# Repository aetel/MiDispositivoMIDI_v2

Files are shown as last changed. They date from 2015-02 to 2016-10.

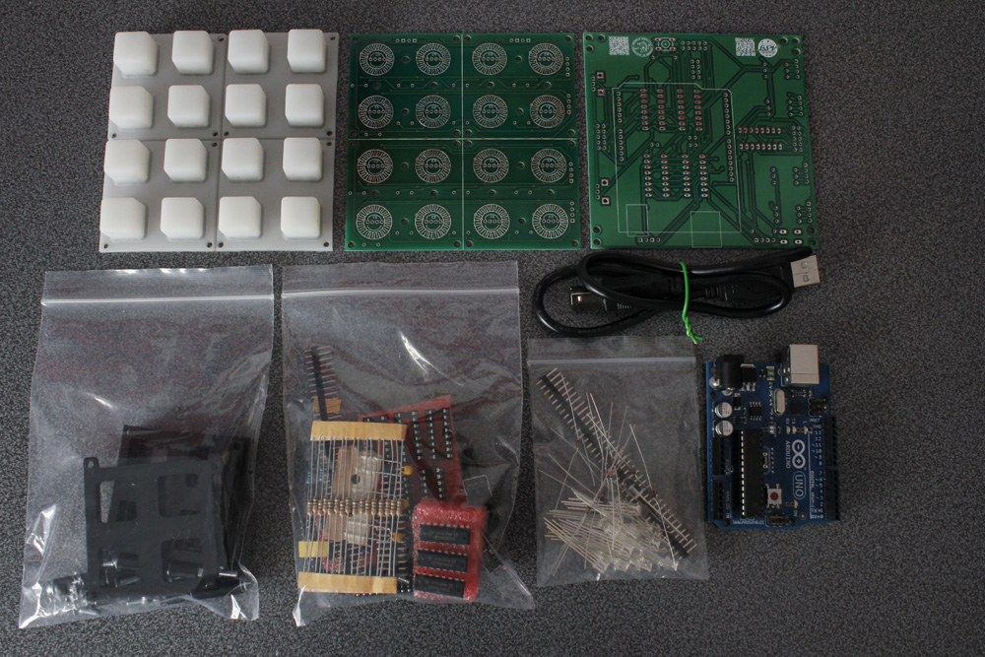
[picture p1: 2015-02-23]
Pictures/00_materials.jpg

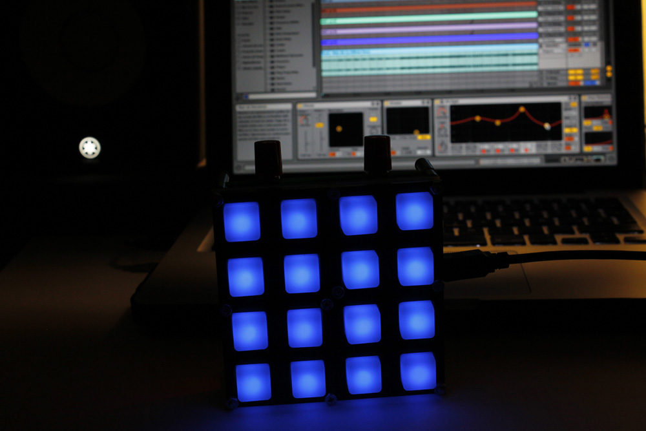
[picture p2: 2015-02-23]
_assembled.jpg

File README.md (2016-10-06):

# Warning
This repository is no loger active. Everything has been moved to the BanaNut Electronics repository:
https://github.com/bananutelectronics

# MiDispositivoMIDI_v2
MiDispositivoMIDI is a DIY MIDI Controller developed by a couple students of the Polytechnic University of Madrid for a workshop given in May and October of 2014. The code is under MIT license and the hardware is under CC BY-NC-SA 4.0. Everything can be downloaded from this repository. If you are interested in helping us to improve our proyect, let us know!

# https://www.facebook.com/midispositivomidi
# midispositivomidi@gmail.com

# Hardware License
<br /><span xmlns:dct="http://purl.org/dc/terms/" property="dct:title">MiDispositivoMIDI</span> by <a xmlns:cc="http://creativecommons.org/ns#" href="https://github.com/midispositivomidi" property="cc:attributionName" rel="cc:attributionURL">Alvaro Lopez Revuelta & Pablo de Miguel Morales</a> is licensed under a <a rel="license" href="http://creativecommons.org/licenses/by-nc-sa/4.0/">Creative Commons Attribution-NonCommercial-ShareAlike 4.0 International License</a>.<br />Permissions beyond the scope of this license may be available at <a xmlns:cc="http://creativecommons.org/ns#" href="https://github.com/midispositivomidi" rel="cc:morePermissions">https://github.com/midispositivomidi</a>.

# Important notes
Note that this Arduino library also uses other libraries. You will need to download the following:
analogmuxdemux.h
SimpleTimer.h
Keypad.h
MIDI.h

# Features
This initial release has four examples in order to show the main features of the library. A brief explanation is given in the header of each example. Basically it shows how to light up the leds, send midi messages and use timmers.

# ChangeLog
-23rd February 2014, v2.0 initial release.

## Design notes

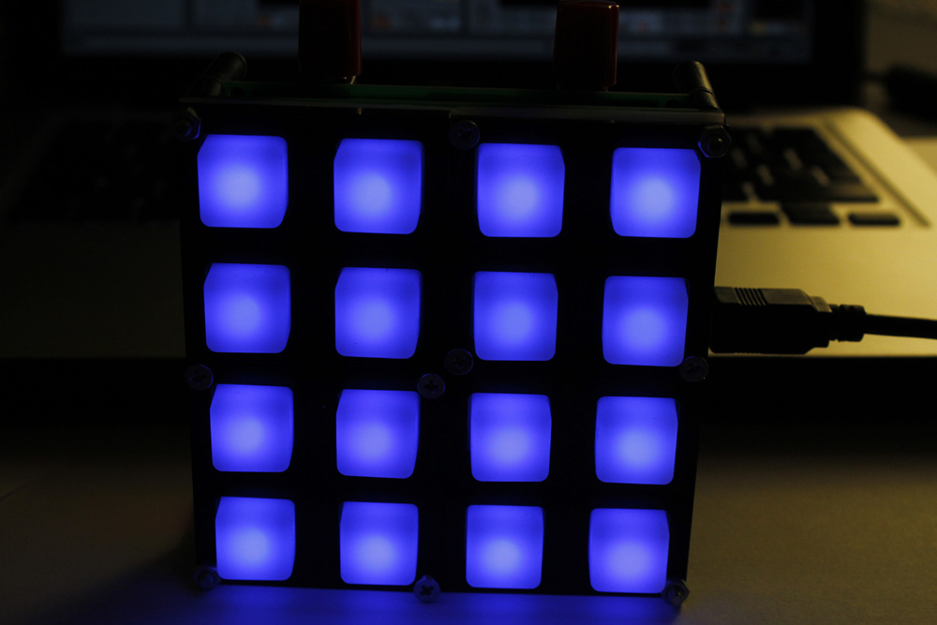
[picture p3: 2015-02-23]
Pictures/00_device.jpg

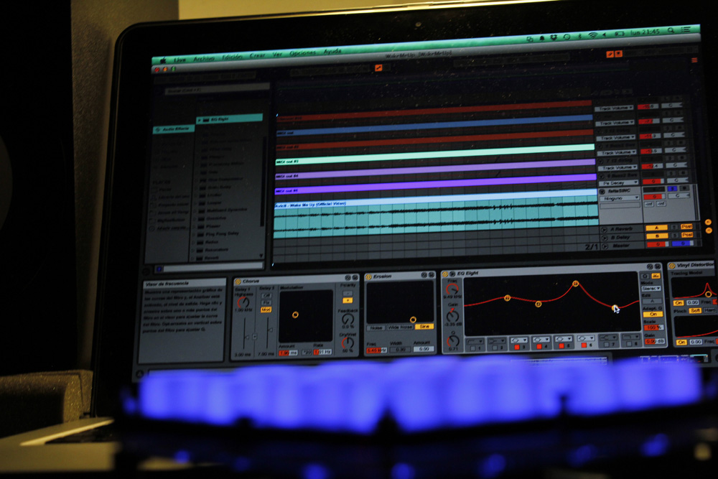
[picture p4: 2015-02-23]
Pictures/00_live2.jpg

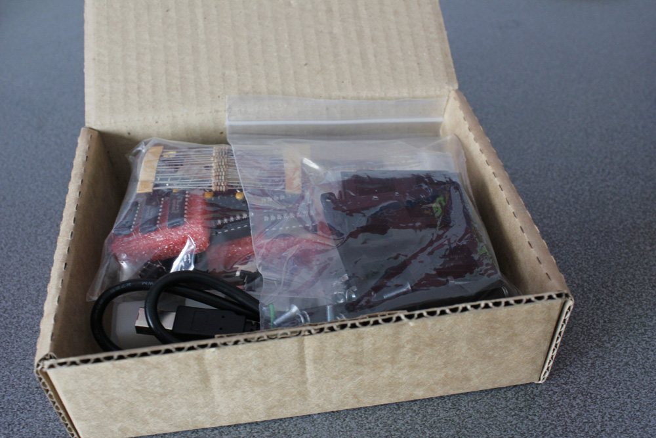
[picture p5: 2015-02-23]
Pictures/00_box.jpg

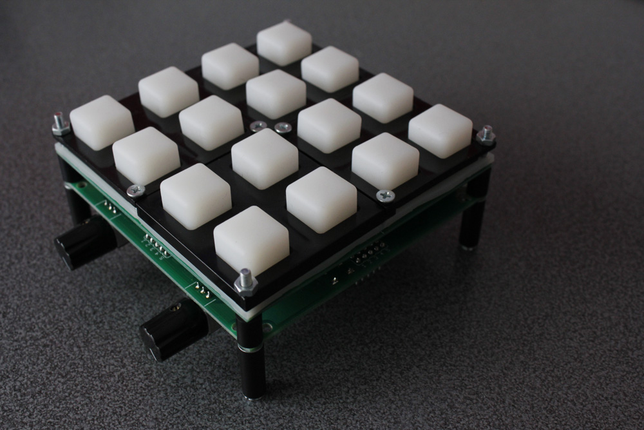
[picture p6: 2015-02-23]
Pictures/00_assempbled.jpg

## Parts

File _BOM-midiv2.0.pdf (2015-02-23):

# Bill of Materials MiDispositivoMidi v2.0

Item | Supplier
x16 LED RGB Diffuse Common Anode | *
x16 Diodes 1N4148 | *
x01 Pin Male (Single row) | *
x02 Male Pin Row (Single and Double) | *
x01 Female Pin Row | *
x01 Top PCB SparkFun | SparkFun website
x01 Bottom PCB | Can’t be bought. See Eagle files
x01 Silicon ButtonPad | SparkFun website
x04 2x2 Bezel | SparkFun website
x06 Screws M3 15mm | *
x04 Screws M3 45mm | *
x04 Tube M3 20mm | *
x04 Tube M3 10mm | *
x10 M3 Nut | *
x08 M3 Washer | *
x02 5k Potentiometer | *
x02 Knob | *
x16 Resistor 220Ohm | *
x02 Resistor 10kOhm | *
x05 DIP 8 | *
x02 Shift Register 74HC595 | *
x03 Multiplexer 4051 | *
x03 Capacitor 0.1uF | *
x02 Switch | *
x02 Jumper | *
x01 Arduino UNO + Cable | *

### *Rows

### marked

### with

an

### asterisk

### can

be

### bought

in

### any

### electronics

### shop. For

### more information

### see

### Eagle

### schematics

or

### MiDispositivoMIDI

guide,

### which

### contains pictures

of

everything.

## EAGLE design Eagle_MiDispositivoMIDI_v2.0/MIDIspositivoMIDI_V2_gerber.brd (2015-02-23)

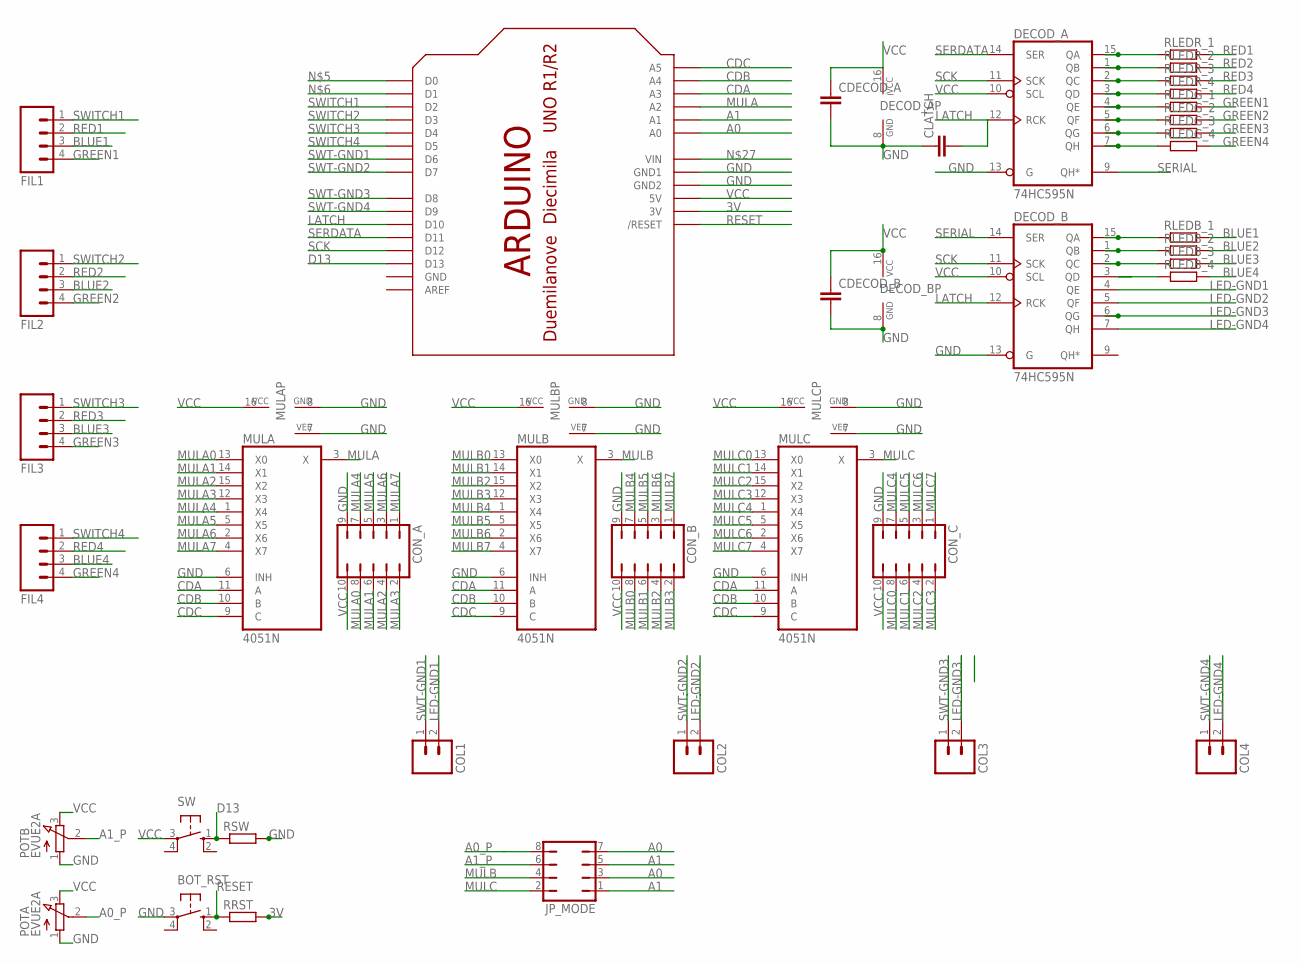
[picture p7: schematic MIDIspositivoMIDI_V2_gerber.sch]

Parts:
BOT_RST: 10-XX; B3F-10XX
CDECOD_A: C-EU025-030X050; C025-030X050
CDECOD_B: C-EU025-030X050; C025-030X050
CLATCH: C-EU025-030X050; C025-030X050
COL1, COL2, COL3, COL4: M02POLAR; MOLEX-1X2
CON_A: JP5Q
CON_B: JP5Q
CON_C: JP5Q
DECOD_A: 74HC595N; DIL16
DECOD_B: 74HC595N; DIL16
FIL1, FIL2, FIL3, FIL4: M04POLAR; MOLEX-1X4
JP_MODE: JP4Q
MULA: 4051N; DIL16
MULB: 4051N; DIL16
MULC: 4051N; DIL16
POTA: EVUE2A; EVUE
POTB: EVUE2A; EVUE
RLEDB_1, RLEDB_2, RLEDB_3, RLEDB_4: R-EU_0207/10; 0207/10
RLEDG_1, RLEDG_2, RLEDG_3, RLEDG_4: R-EU_0207/10; 0207/10
RLEDR_1, RLEDR_2, RLEDR_3, RLEDR_4: R-EU_0207/10; 0207/10
RRST: R-EU_0207/10; 0207/10
RSW: R-EU_0207/10; 0207/10
SW: 10-XX; B3F-10XX
U$1: ARDUINO-NOHOLE

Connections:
3V: RRST.2, U$1.3V
A0: JP_MODE.3, JP_MODE.7, U$1.A0
A0_P: JP_MODE.8, POTA.2 (S)
A1: JP_MODE.1, JP_MODE.5, U$1.A1
A1_P: JP_MODE.6, POTB.2 (S)
BLUE1: FIL1.3, RLEDB_1.2
BLUE2: FIL2.3, RLEDB_2.2
BLUE3: FIL3.3, RLEDB_3.2
BLUE4: FIL4.3, RLEDB_4.2
CDA: MULA.11 (A), MULB.11 (A), MULC.11 (A), U$1.A3
CDB: MULA.10 (B), MULB.10 (B), MULC.10 (B), U$1.A4
CDC: MULA.9 (C), MULB.9 (C), MULC.9 (C), U$1.A5
D13: RSW.1, SW.1 (S), U$1.D13
GND: BOT_RST.3, CDECOD_A.2, CDECOD_B.2, CLATCH.1, CON_A.9, CON_B.9, CON_C.9, DECOD_A.8 (GND), DECOD_A.13 (G), DECOD_B.8 (GND), DECOD_B.13 (G), MULA.6 (INH), MULA.7 (VEE), MULA.8 (GND), MULB.6 (INH), MULB.7 (VEE), MULB.8 (GND), MULC.6 (INH), MULC.7 (VEE), MULC.8 (GND), POTA.1 (A), POTB.1 (A), RSW.2, U$1.GND, U$1.GND1, U$1.GND2
GREEN1: FIL1.4, RLEDG_1.2
GREEN2: FIL2.4, RLEDG_2.2
GREEN3: FIL3.4, RLEDG_3.2
GREEN4: FIL4.4, RLEDG_4.2
LATCH: CLATCH.2, DECOD_A.12 (RCK), DECOD_B.12 (RCK), U$1.D10
LED-GND1: COL1.2, DECOD_B.4 (QE)
LED-GND2: COL2.2, DECOD_B.5 (QF)
LED-GND3: COL3.2, DECOD_B.6 (QG)
LED-GND4: COL4.2, DECOD_B.7 (QH)
MULA: MULA.3 (X), U$1.A2
MULA0: CON_A.8, MULA.13 (X0)
MULA1: CON_A.6, MULA.14 (X1)
MULA2: CON_A.4, MULA.15 (X2)
MULA3: CON_A.2, MULA.12 (X3)
MULA4: CON_A.7, MULA.1 (X4)
MULA5: CON_A.5, MULA.5 (X5)
MULA6: CON_A.3, MULA.2 (X6)
MULA7: CON_A.1, MULA.4 (X7)
MULB: JP_MODE.4, MULB.3 (X)
MULB0: CON_B.8, MULB.13 (X0)
MULB1: CON_B.6, MULB.14 (X1)
MULB2: CON_B.4, MULB.15 (X2)
MULB3: CON_B.2, MULB.12 (X3)
MULB4: CON_B.7, MULB.1 (X4)
MULB5: CON_B.5, MULB.5 (X5)
MULB6: CON_B.3, MULB.2 (X6)
MULB7: CON_B.1, MULB.4 (X7)
MULC: JP_MODE.2, MULC.3 (X)
MULC0: CON_C.8, MULC.13 (X0)
MULC1: CON_C.6, MULC.14 (X1)
MULC2: CON_C.4, MULC.15 (X2)
MULC3: CON_C.2, MULC.12 (X3)
MULC4: CON_C.7, MULC.1 (X4)
MULC5: CON_C.5, MULC.5 (X5)
MULC6: CON_C.3, MULC.2 (X6)
MULC7: CON_C.1, MULC.4 (X7)
unnamed: DECOD_A.15 (QA), RLEDR_1.1
unnamed: DECOD_A.1 (QB), RLEDR_2.1
unnamed: DECOD_A.2 (QC), RLEDR_3.1
unnamed: DECOD_A.3 (QD), RLEDR_4.1
unnamed: DECOD_A.4 (QE), RLEDG_1.1
unnamed: DECOD_A.5 (QF), RLEDG_2.1
unnamed: DECOD_A.6 (QG), RLEDG_3.1
unnamed: DECOD_A.7 (QH), RLEDG_4.1
unnamed: DECOD_B.15 (QA), RLEDB_1.1
unnamed: DECOD_B.1 (QB), RLEDB_2.1
unnamed: DECOD_B.2 (QC), RLEDB_3.1
unnamed: DECOD_B.3 (QD), RLEDB_4.1
RED1: FIL1.2, RLEDR_1.2
RED2: FIL2.2, RLEDR_2.2
RED3: FIL3.2, RLEDR_3.2
RED4: FIL4.2, RLEDR_4.2
RESET: BOT_RST.1 (S), RRST.1, U$1.RESET (/RESET)
SCK: DECOD_A.11 (SCK), DECOD_B.11 (SCK), U$1.D12
SERDATA: DECOD_A.14 (SER), U$1.D11
SERIAL: DECOD_A.9 (QH*), DECOD_B.14 (SER)
SWITCH1: FIL1.1, U$1.D2
SWITCH2: FIL2.1, U$1.D3
SWITCH3: FIL3.1, U$1.D4
SWITCH4: FIL4.1, U$1.D5
SWT-GND1: COL1.1, U$1.D6
SWT-GND2: COL2.1, U$1.D7
SWT-GND3: COL3.1, U$1.D8
SWT-GND4: COL4.1, U$1.D9
VCC: CDECOD_A.1, CDECOD_B.1, CON_A.10, CON_B.10, CON_C.10, DECOD_A.10 (SCL), DECOD_A.16 (VCC), DECOD_B.10 (SCL), DECOD_B.16 (VCC), MULA.16 (VCC), MULB.16 (VCC), MULC.16 (VCC), POTA.3 (E), POTB.3 (E), SW.3, U$1.5V

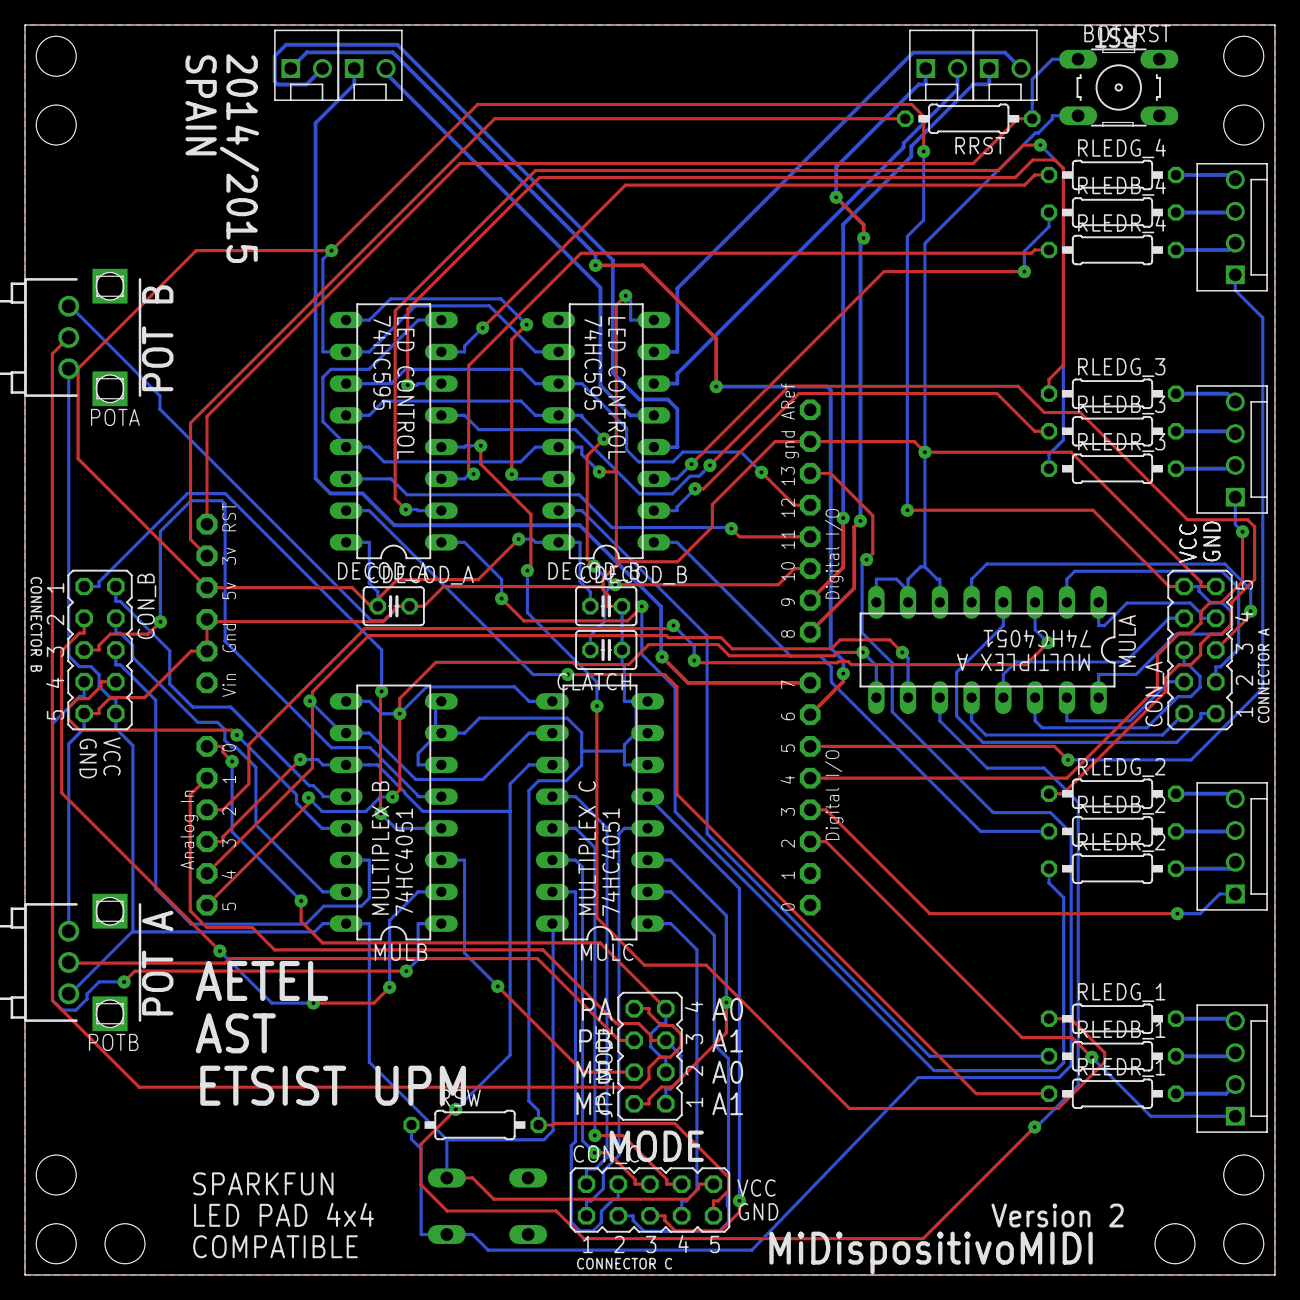
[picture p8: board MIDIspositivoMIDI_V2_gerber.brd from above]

Board: 2 copper layers, 100.0 x 100.0 mm, 39 parts (1 on the bottom side), 79 nets.

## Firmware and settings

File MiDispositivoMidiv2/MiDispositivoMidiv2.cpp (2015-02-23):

#include "Arduino.h"
#include "MiDispositivoMidiv2.h"

const int latchPin = 10;
const int dataPin = 11;
const int clockPin = 12;

// Estas variables almacenaran en hexadecimal los valores necesarios
// para representar en los led lo que se quiera
char parteAlta = 0x00;
char parteBaja = 0x00;


byte dataArrayRG[4]; // Datos RED GREEN
byte dataArrayBC[4]; // Datos BLUE y COL
byte dataRG;
byte dataBC;
#define RED 1
#define BLU 0
#define GRN 2
int anodoComun = 1;  //cambiar anodo o catodo comun.  anodo =1

// Almacenara los valores de los led que se quieran encender
int ledMatrix[4][4][3]={
    {{0,0,0},{0,0,0},{0,0,0},{0,0,0},}, // RGB
    {{0,0,0},{0,0,0},{0,0,0},{0,0,0},},
    {{0,0,0},{0,0,0},{0,0,0},{0,0,0},},
    {{0,0,0},{0,0,0},{0,0,0},{0,0,0},},
};

// Constructor de nuestro dispositivo
MiDispositivoMidiv2::MiDispositivoMidiv2()
{
    // Se ponen asignan los pines para los registros de desplazamiento como salidas
    pinMode(latchPin, OUTPUT);
    pinMode(dataPin, OUTPUT);
    pinMode(clockPin, OUTPUT);
    //Se encinden los leds con el valor inicial de las variables
    // parteAlta y parteBaja. Este valor hace que esten apagados
}


//--------------PARA LOS LEDS---------------------//

void MiDispositivoMidiv2::setCommonAnode(){
    anodoComun = 1;
}
void MiDispositivoMidiv2::setCommonCathode(){
    anodoComun = 0;
}

void MiDispositivoMidiv2::turnOn(){
    //Apaga la salida para que al realizar el desplazamiento no se vea
    digitalWrite(latchPin, LOW);
    //Lleva los datos a los registros
    if(!anodoComun){  //si es de catodo comun en vez de anodo comun
        parteBaja = ~parteBaja;
        parteAlta = ~parteAlta;
    }
    shiftOut(dataPin, clockPin, LSBFIRST, parteBaja);
    shiftOut(dataPin, clockPin, LSBFIRST, parteAlta);
    // turn on the output so the LEDs can light up:
    digitalWrite(latchPin, HIGH);
}
//Lleva a los registros de desplazamiento todos los datos necesarios para iluminar los leds
void MiDispositivoMidiv2::setLed(char alta, char baja){
    parteAlta=alta;
    parteBaja=baja;
    turnOn();
}
//Enciende todo de un mismo color
void MiDispositivoMidiv2::lightUpAll(char color){
    if(color=='b'){
        setLed(0xF0,0xFF);
    }
    if(color=='r'){
        setLed(0x0F,0xFF);
    }
    if(color=='g'){
        setLed(0xFF,0x0F);
    }
    if(color=='y'){
        setLed(0x0F,0x0F);
    }
    if(color=='m'){
        setLed(0x00,0xFF);
    }
    if(color=='c'){
        setLed(0xF0,0x0F);
    }
    if(color=='w'){
        setLed(0x00,0x0F);
    }
}
//Enciende una fila de un determinado color
void MiDispositivoMidiv2::lightUpRow(char color, int fila ){
    if(color=='b'){ //Color azul
        if(fila==1){setLed(0xFE,0xFF);}
        if(fila==2){setLed(0xFD,0xFF);}
        if(fila==3){setLed(0xFB,0xFF);}
        if(fila==4){setLed(0xF7,0xFF);}
    }if(color=='r'){ //Color rojo
        if(fila==1){setLed(0xEF,0xFF);}
        if(fila==2){setLed(0xDF,0xFF);}
        if(fila==3){setLed(0xBF,0xFF);}
        if(fila==4){setLed(0x7F,0xFF);}
    }if(color=='g'){ //Color verde
        if(fila==1){setLed(0xFF,0xEF);}
        if(fila==2){setLed(0xFF,0xDF);}
        if(fila==3){setLed(0xFF,0xBF);}
        if(fila==4){setLed(0xFF,0x7F);}
    }
    if(color=='y'){ //Color amarillo = verde + rojo
        if(fila==1){setLed(0xEF,0xEF);}
        if(fila==2){setLed(0xDF,0xDF);}
        if(fila==3){setLed(0xBF,0xBF);}
        if(fila==4){setLed(0x7F,0x7F);}
    }
    if(color=='m'){ //Color magenta = rojo + azul
        if(fila==1){setLed(0xEE,0xFF);}
        if(fila==2){setLed(0xDD,0xFF);}
        if(fila==3){setLed(0xBB,0xFF);}
        if(fila==4){setLed(0x77,0xFF);}
    }
    if(color=='c'){ //Color cyan = verde + azul
        if(fila==1){setLed(0xFE,0xEF);}
        if(fila==2){setLed(0xFD,0xDF);}
        if(fila==3){setLed(0xFB,0xBF);}
        if(fila==4){setLed(0xF7,0x7F);}
    }
    if(color=='w'){ //Color blanco = verde + rojo + azul
        if(fila==1){setLed(0xEE,0xEF);}
        if(fila==2){setLed(0xDD,0xDF);}
        if(fila==3){setLed(0xBB,0xBF);}
        if(fila==4){setLed(0x77,0x7F);}
    }
}

//Enciende una columna de un determinado color
void MiDispositivoMidiv2::lightUpCol(char color, int columna){
    if(color=='b'){ //Color azul
        if(columna==1){setLed(0xF0,0xF8);}
        if(columna==2){setLed(0xF0,0xF4);}
        if(columna==3){setLed(0xF0,0xF2);}
        if(columna==4){setLed(0xF0,0xF1);}
    }if(color=='r'){ //Color rojo
        if(columna==1){setLed(0x0F,0xF8);}
        if(columna==2){setLed(0x0F,0xF4);}
        if(columna==3){setLed(0x0F,0xF2);}
        if(columna==4){setLed(0x0F,0xF1);}
    }if(color=='g'){ //Color verde
        if(columna==1){setLed(0xFF,0x08);}
        if(columna==2){setLed(0xFF,0x04);}
        if(columna==3){setLed(0xFF,0x02);}
        if(columna==4){setLed(0xFF,0x01);}
    }
    if(color=='y'){ //Color amarillo = verde + rojo
        if(columna==1){setLed(0x0F,0x08);}
        if(columna==2){setLed(0x0F,0x04);}
        if(columna==3){setLed(0x0F,0x02);}
        if(columna==4){setLed(0x0F,0x01);}
    }
    if(color=='m'){ //Color magenta = rojo + azul
        if(columna==1){setLed(0x00,0xF8);}
        if(columna==2){setLed(0x00,0xF4);}
        if(columna==3){setLed(0x00,0xF2);}
        if(columna==4){setLed(0x00,0xF1);}
    }
    if(color=='c'){ //Color cyan = verde + azul
        if(columna==1){setLed(0xF0,0x08);}
        if(columna==2){setLed(0xF0,0x04);}
        if(columna==3){setLed(0xF0,0x02);}
        if(columna==4){setLed(0xF0,0x01);}
    }
    if(color=='w'){ //Color blanco = verde + azul + rojo
        if(columna==1){setLed(0x00,0x08);}
        if(columna==2){setLed(0x00,0x04);}
        if(columna==3){setLed(0x00,0x02);}
        if(columna==4){setLed(0x00,0x01);}
    }
}
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

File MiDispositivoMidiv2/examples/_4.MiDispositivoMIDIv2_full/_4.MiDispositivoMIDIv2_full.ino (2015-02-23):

/****-------------------- MIDISPOSITIVOMIDI V2.0 --------------------****
* This is a simple code to MiDispositivoMidi v2.0, a DIY MIDI Controller
* developed by Pablo de Miguel Morales and Alvaro Lopez Revuelta at the
* Polythecnical University of Madrid, for a workshop given in 2014.
* This code was developed by Alvaro Lopez Revuelta for the project MiDispositivoMidi v2.0
* and uses the function "formar_array" of Pablo de Miguel Morales
*
*                            Feel free to contact us:
*                            midispositivomidi@gmail.com
*                        https://github.com/midispositivomidi
*                     https://www.facebook.com/midispositivomidi
*           For further information about the license, visit us on GitHub                      
*
* Features of Example 4:
* It also uses our Arduino library (MiDispositivoMidiv2.h) for led handling
* The main functionalities are:
*    -Send MIDI Messages that can be setted by the user
*    -It has seven pages of notes/colors
*    -Pressed--->Send NoteOn
*    -Released-->Send NoteOff
*    -The user can also set the color of each page
*    -and the color of each pressed button
*/
#include <analogmuxdemux.h>
#include <SimpleTimer.h>
#include <MiDispositivoMidiv2.h>
#include <Keypad.h>
#include <MIDI.h>
#define NO_PINS 8
#define R 1
#define G 2
#define B 3
#define Y 4
#define C 5
#define M 6
#define W 7

/*--------------------------C U S T O M I Z E  T H E  C O D E---------------------------*/

/* In this arrays bellow, you can customize the code by selecting which note
*  wil be sent pressing each button, what colour do you want on each page, and
*  what colour do you want to light up when pressed. Also you can set how many
*  expansions you want to use (from 0 to 3);
*/

#define N_EXP 0                          //If 2 or 3 is selected, lateral pots (2) wont work
#define MAX_NUM_PAGES 7                  //Change the array length if you change this value
#define DEFAULT_PAGE 0                   //This is the page shown after botting (default page)
int led_pages[4][MAX_NUM_PAGES][4] = {   //Colour of each page when no button is pressed
 //pag 1    //pag 2   //pag 3   //pag 4   //pag 5   //pag 6   //pag 7
{{B,B,B,B},{G,G,G,G},{B,B,B,B},{Y,Y,Y,Y},{C,C,C,C},{M,M,M,M},{W,W,W,W}},
{{B,B,B,B},{G,G,G,G},{B,B,B,B},{Y,Y,Y,Y},{C,C,C,C},{M,M,M,M},{W,W,W,W}},
{{B,B,B,B},{G,G,G,G},{B,B,B,B},{Y,Y,Y,Y},{C,C,C,C},{M,M,M,M},{W,W,W,W}},
{{B,B,B,B},{G,G,G,G},{B,B,B,B},{Y,Y,Y,Y},{C,C,C,C},{M,M,M,M},{W,W,W,W}},
};

int led_pressed[4][MAX_NUM_PAGES][4] = {  //Colour when pressed. When released it will be the same as before
 //pag 1    //pag 2   //pag 3   //pag 4   //pag 5   //pag 6   //pag 7
{{G,G,G,G},{R,R,R,R},{R,R,R,R},{R,R,R,R},{R,R,R,R},{R,R,R,R},{R,R,R,R}},
{{G,G,G,G},{R,R,R,R},{R,R,R,R},{R,R,R,R},{R,R,R,R},{R,R,R,R},{R,R,R,R}},
{{G,G,G,G},{R,R,R,R},{R,R,R,R},{R,R,R,R},{R,R,R,R},{R,R,R,R},{R,R,R,R}},
{{G,G,G,G},{R,R,R,R},{R,R,R,R},{R,R,R,R},{R,R,R,R},{R,R,R,R},{R,R,R,R}},
};

int notes[4][MAX_NUM_PAGES][4] = {       //Here you can set which note do you want to send
  //pag 1       //pag 2        //pag 3       //pag 4       //pag 5      //pag 6       //pag 7
{{0 ,1 ,2 , 3},{16,17,18,19},{32,33,34,35},{48,49,50,51},{64,65,66,67},{80,81,82,83},{96 , 97 ,98 ,99}},
{{4 ,5 ,6 , 7},{20,21,22,23},{36,37,38,39},{52,53,54,55},{68,69,70,71},{84,85,86,87},{100,101,102,103}},
{{8 ,9 ,10,11},{24,25,26,27},{40,41,42,43},{56,57,58,59},{72,73,74,75},{88,89,90,91},{104,105,106,107}},
{{12,13,14,15},{28,29,30,31},{44,45,46,47},{60,61,62,63},{76,77,78,79},{92,93,94,95},{108,109,110,110}},
};
/* --------------------------end of customizing code---------------------------------------*/


uint16_t prev_expA[8]={0,0,0,0,0,0,0,0}; //Last value read of potExpansion A
uint16_t prev_expB[8]={0,0,0,0,0,0,0,0}; //Last value read of potExpansion B
uint16_t prev_expC[8]={0,0,0,0,0,0,0,0}; //Last value read of potExpansion C
int num_page = 0;                        //Current page (from 1 to 7)
int prev_integrated0 = 0;                //For integrated pots
int prev_integrated1 = 0;
int pushedRow=0;                         //Coordinate y of pressed button
int pushedCol=0;                         //Coordinate x of pressed button
int contador1 = 0;                       //Counter for one timmer
boolean shift_pushed =false;

AnalogMux Amux(17,18,19, 2); //EXP
AnalogMux Bmux(17,18,19, 0); //EXP
AnalogMux Cmux(17,18,19, 1); //EXP

SimpleTimer timer;
SimpleTimer timer2;
MiDispositivoMidiv2 ledhandling;
MIDI_CREATE_DEFAULT_INSTANCE();
byte rowPins[4] = {5, 4, 3, 2}; //connect to the row pinouts of the kpd
byte colPins[4] = {6, 7, 8, 9}; //connect to the column pinouts of the kpd
char keys[4][4] = {
{'a','b','c','d'},
{'e','f','g','h'},
{'i','j','k','l'},
{'m','n','o','p'}
};
Keypad kpd = Keypad( makeKeymap(keys), rowPins, colPins, 4, 4 );
int current_page[4][4] = {   //Colors values of currentPage
{1,1,1,1},
{1,1,1,1},
{1,1,1,1},
{1,1,1,1}
};

void setup() {
  //Serial.begin(115200);    //Use this to debug with hairless
  MIDI.begin(0);         //or this if you are using HIDUINO firmware
  pinMode(13,OUTPUT);

  ledhandling.setCommonAnode(); //Or Common.Cathod()
  
  timer.setInterval(1, repeatMe);
  timer2.setInterval(1, repeatMe2);
  for(int i=0; i<4; i++){ //Initialice the array
    for (int j=0;j<4; j++){
      current_page[i][j] = led_pages[i][DEFAULT_PAGE][j];
    }  
  }
  //Welcome animation
  for(int i=1;i<5;i++){
    for (int j=1;j<5;j++){
      ledhandling.lightUpDir(i,j,'g');
      delay(50);    
      ledhandling.lightUpDir(i,j,'w'); 
      delay(50); 
     } 
   }
}

void loop() {
  //timer.run();
  //timer2.run()
  readPageNum(); //Read page number (1 to 7). Also set the colors to current_page                
  ledhandling.lightUpArray(current_page); //Light up them
      if (kpd.getKeys()){
        for (int i=0; i<LIST_MAX; i++){   //Scan the whole list
            if ( kpd.key[i].stateChanged ){ //Only keys that have changed
              getPushedButton(kpd.key[i].kchar); //Get the value of pushedRow/Col
                switch (kpd.key[i].kstate) {  // Report active key state : IDLE, PRESSED, HOLD, or RELEASED
                    case PRESSED:
                      MIDI.sendNoteOn(notes[pushedRow][num_page][pushedCol],127,1); //Send the note defined by the user at the begining
                      refreshButtonStatePressed();//Update the colours to lightup the one that was pushed
                break;
                    case HOLD:
                      //Empty
                break;
                    case RELEASED:
                      //Serial.println(button); //debug
                      MIDI.sendNoteOff(notes[pushedRow][num_page][pushedCol],0,1);
                      refreshButtonStateReleased();
                      // Serial.println(button); //Debug
                //break;
                  //  case IDLE:
                    //Serial.println('Debug');
                }
            }
        }
    }
allPots();  //Read all pots (depending on the number of exp)
}//End Loop

void repeatMe() { //Led routine 1. Currently disabled
  contador1++;
  if(contador1<150){ledhandling.lightUpCol('w',1);
  }else if(contador1<300){ledhandling.lightUpCol('w',2);
  }else if(contador1<450){ledhandling.lightUpCol('w',3);
  }else if(contador1<600){ledhandling.lightUpCol('w',4);
  }else if(contador1<750){ledhandling.lightUpCol('w',3);
  }else if(contador1<900){ledhandling.lightUpCol('w',2);
  }else{contador1=0;}
}

void repeatMe2(){ //Led routine 2. Currently disabled
 ledhandling.lightUpDir(1,1,'r'); 
}

void readPageNum(){
 if(digitalRead(13)){
   if(!shift_pushed){
   shift_pushed=true;
     if(num_page<(MAX_NUM_PAGES-1)){
       num_page++;
       readCurrentPage();
   }else{num_page=0;readCurrentPage();
   }
   }
 }if(!digitalRead(13)){shift_pushed=false;}
}


void readCurrentPage(){
  for(int i=0; i<4; i++){
    for(int j=0;j<4;j++){
      current_page[i][j] = led_pages[i][num_page][j];
  } 
 } 
}

void getPushedButton(char button){
  if(button=='a'){pushedRow=0;pushedCol=0;}
  if(button=='b'){pushedRow=0;pushedCol=1;}
  if(button=='c'){pushedRow=0;pushedCol=2;}
  if(button=='d'){pushedRow=0;pushedCol=3;}
  if(button=='e'){pushedRow=1;pushedCol=0;}
  if(button=='f'){pushedRow=1;pushedCol=1;}
  if(button=='g'){pushedRow=1;pushedCol=2;}
  if(button=='h'){pushedRow=1;pushedCol=3;}
  if(button=='i'){pushedRow=2;pushedCol=0;}
  if(button=='j'){pushedRow=2;pushedCol=1;}
  if(button=='k'){pushedRow=2;pushedCol=2;}
  if(button=='l'){pushedRow=2;pushedCol=3;}
  if(button=='m'){pushedRow=3;pushedCol=0;}
  if(button=='n'){pushedRow=3;pushedCol=1;}
  if(button=='o'){pushedRow=3;pushedCol=2;}
  if(button=='p'){pushedRow=3;pushedCol=3;}
}

void refreshButtonStatePressed(){
  current_page[pushedRow][pushedCol] = led_pressed[pushedRow][num_page][pushedCol];
}

void refreshButtonStateReleased(){
  current_page[pushedRow][pushedCol] = led_pages[pushedRow][num_page][pushedCol];
}

void allPots(){
  uint16_t valA = 0;
  uint16_t valB = 0;
  uint16_t valC = 0;
    for (int pinno=0; pinno < NO_PINS; pinno++){
      Amux.SelectPin(pinno); //se usa solo uno. Los pines de control son los mismos
      Bmux.SelectPin(pinno);
      Cmux.SelectPin(pinno);
      if (N_EXP == 0){
        integratedPots();
      }
      if(N_EXP == 1){
        valA = ceil((Amux.AnalogRead())/8);
        if (valA != prev_expA[pinno]){
          MIDI.sendControlChange(pinno+2, valA,1); //chanel 0
          prev_expA[pinno] = valA;
        }
      }else if (N_EXP == 2){
        valA = ceil((Amux.AnalogRead())/8);
        valB = ceil((Bmux.AnalogRead())/8);
        if (valA != prev_expA[pinno]){
          MIDI.sendControlChange(pinno+2, valA,1); //chanel 0
          prev_expA[pinno] = valA; 
        }
        if (valB != prev_expB[pinno]){
          MIDI.sendControlChange(pinno+10, valB,1); //chanel 0
          prev_expB[pinno] = valB; 
        }
        
        
      }else if (N_EXP ==3){
        valA = ceil((Amux.AnalogRead())/8);
        valB = ceil((Bmux.AnalogRead())/8);
        valC = ceil((Cmux.AnalogRead())/8);
        if (valA != prev_expA[pinno]){
          MIDI.sendControlChange(pinno+2, valA,1);  //chanel 0
          prev_expA[pinno] = valA;
        }
        if (valB != prev_expB[pinno]){
          MIDI.sendControlChange(pinno+10, valB,1); //chanel 0
          prev_expB[pinno] = valB; 
        }
        if (valC != prev_expC[pinno]){
          MIDI.sendControlChange(pinno+18, valC,1); //chanel 0
          prev_expC[pinno] = valC; 
        }
      }    
    }
}

void integratedPots(){
  uint16_t value0 = 0;
  uint16_t value1 = 0;
  
  value0 = ceil(analogRead(0)/8);
  value1 = ceil(analogRead(1)/8);
  
  if (value0 != prev_integrated0){
    MIDI.sendControlChange(0, value0,1);
  }
  if(value1 != prev_integrated1){
    MIDI.sendControlChange(1, value1,1);
  }
  
  prev_integrated0 = value0;
  prev_integrated1 = value1;
}
